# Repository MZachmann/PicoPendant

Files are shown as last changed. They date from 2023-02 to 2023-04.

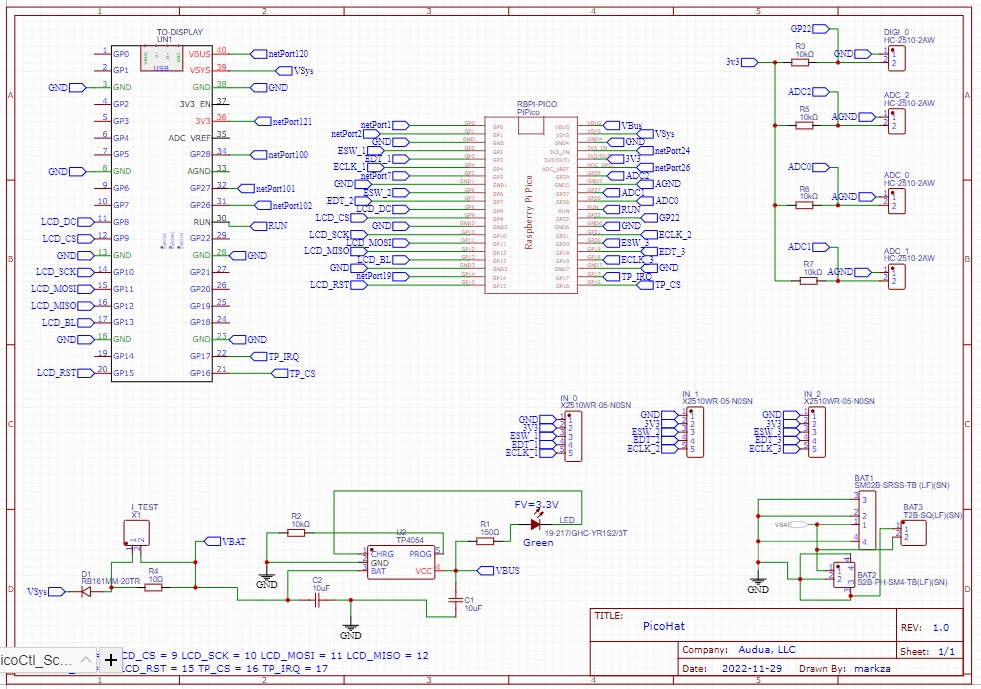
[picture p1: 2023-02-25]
CircuitBoard/images/Schematic_V1_02.jpg

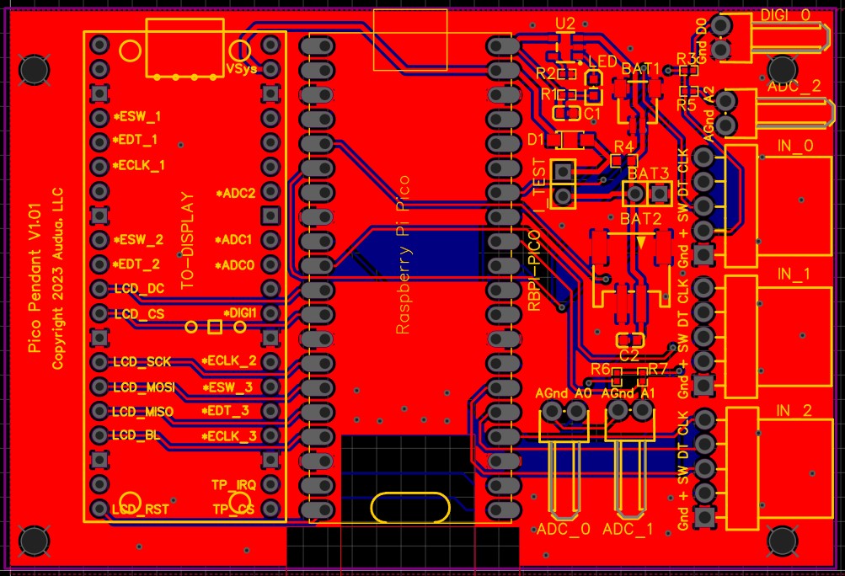
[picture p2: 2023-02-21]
CircuitBoard/images/PCB_Top_V1_01.jpg

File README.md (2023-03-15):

# PicoPendant
A small wireless CNC Pendant based off the Raspberry Pi Pico W and the Waveshare Pico-ResTouch-LCD-3.5. 

The pendant uses WiFi to communicate with the CNC and can work with any CNC/Mill/3d printer device that is available on a network. The current Micropython source only supports Duet3d-based controllers because that's all I have.

## Folders
* CircuitBoard<br>This contains the circuit board (display hat) files and readme. The circuit board has two LiPo connectors (small and regular), a LiPo charger, three encoder inputs, three A/D dividers for ladder switches and one switch input.
* Enclosure<br>This contains a Fusion360 workspace and result STL files for 3d printing an enclosure and spacers. The spacers are used to support the display hat over the Waveshare LCD. Since the hole locations are not exact and Jlcpcb seems unable to put holes in the right place anyway, the spacers are slightly offset.
* PythonSrc<br>The MicroPython source code

## Getting Started

You may need to install a driver to have the Pico show up as a serial port. See the Raspberry Pi Pico documentation.

### Installing MicroPython
* Plug the Pico into a USB port.
* Boot the Pico W. If it's connected to the display use the display reboot button, otherwise just power up the USB port.
* While booting, hold down the white button on top of the Pico. This will attach a drive to the PC.
* Copy the latest Micropython UF2 file to the attached Pico drive. When the copy is complete the Pico will reboot and Python will be installed.

### Start up Visual Studio Code
* Install Visual Studio Code
* Add these extensions (at least)
  * Python - adds intellisense for python
  * Pymakr - this plugin adds USB serial support for the Pico
* Start up Visual Studio Code and open the source folder. You should be prompted to load the PicoPendant.code-workspace as a Workspace and that links in the Pymakr usb serial extensions.

### Synching and copying files
* In Visual Studio Code switch to the pymakr extension icon in the left toolbar
* You may need to select the Pico COM port (ensure any driver is installed)
* As you mouse over the USB Serial Device line under PROJECTS / PicoPendant you'll see some icons appear (yeah bad UI)
  * Click the lightning bolt icon to connect to the Pico USB Serial
  * Click the box/prompt icon to open a terminal connected to the Pico
* To copy a file to the Pico:
  * Right click the file name and use the pymakr menu to select Upload to device
* To synchronize all files to the pico:
  * Mouse over the USB Serial Device line in the pymakr extension and pick the arrow-to-cloud icon (yeah bad UI)

### config.json
The code sets up default globals then reads config.json to override them. It's simple to manually edit your config.json and set up networking variables. Put config.json in the root with main.py to have it loaded at startup. Interrupt (Ctrl-C) the running jog.py and use

	from util import picoPendant
	picoPendant.GlobalPico().Save()

to save current settings. Clean out the stuff you don't want changed, then edit the stuff you want to override.

## SBC Support
The SBC version of the Duet3d controller takes quite a different WiFi syntax and is not yet supported.

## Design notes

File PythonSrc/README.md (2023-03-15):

# PicoPendant

## Overview
PicoPendant is a very simple product. It contains a Raspberry Pi Pico W, a [optional touchscreen] display, and a board that provides support for a LiPo alternate power source with charger from the USB. The board also has output pins providing raw access to most of the unused Pico I/O pins in a form for easy attachment to rotary encoders, ladder switches and other simple I/O devices.

The micropython source workspace (this) uses the __pymakr__ Visual Studio Code extension to communicate with the Pico W. It can synchronize files between the Pico W and PC and is generally very convenient but a bit awkward.

## Source
The source is all standard __MicroPython__. It is divided into functional groups. I attempted to use asynchronous I/O and a thread and both attempts failed miserably. Either it was running out of memory or too slow or ... anyway I pulled that stuff all out and it's just all blocking I/O for now. Maybe over time the threading will improve because network threaded is so obvious.

## GUI
The current gui is a single screen named 'Jog'. To run the jog screen requires the following MicroPython

	import runjog

The current GUI supports two rotary encoders and one ladder switch.

The leftmost encoder does the jogging. Click the switch to move between metric and inches and also to show/hide machine coordinates, so four positions.

The middle encoder is multi-use but primarily sets the jog amount per click. When the button is clicked the jog amount becomes enabled/disabled and an asterisk appears - this is a safety measure. If the middle encoder is disabled then tapping the touchscreen is also disabled.

The right switch sets the axis being jogged. 

To switch devices, tap the touchscreen and the middle encoder mode changes to device select. Tap again to have the middle encoder change screen brightness. Tap one more time to return to jog amount selection.

To exit cleanly from RunJogger press both rotary encoder buttons at the same time.

<span style="color:orange">There are 2 'safety' things to ensure the jogger isn't fussing your machine during jobs.</span>
* it only sends wifi requests when the encoder mode is 'adjust tic size' (enabled or disabled)
* you can use a Null device (0.0.0.0) to disable wifi requests

## Serialization
There is code to serialize/load the current settings. The load happens at start (main.py) but currently there is no automatic configuration save so that is a manual python call.

	from util import picoPendant
	picoPendant.GlobalPico().Save()

The configuration loader reads config.json and updates any fields found in config.json that exist in GlobalPico()).

## Known Concerns
* Touchscreen<br>
Currently the touchscreen location can not be read because this requires a much slower SPI speed and trying to temporarily switch the SPI speed to accomodate the touch location reader causes WiFi, which also uses SPI, to start failing permanently. So for now the touch location is not used. 
* Performance<br>
At this point I've switched to asyncio for the networking since threads were never going to work afaik. This works remarkably well so just tweaky timing things now.
* Rotary Encoders<br>
The current switch-based encoders are pretty weak (coarse and rare step-loss) but very cheap - the usual tradeoff. Using a real optical encoder for the movement rotary would help and I may switch to that at some point since I have one lying around.
* MicroPython<br>
Both MicroPython and CircuitPython are still in beta for the Raspberry Pi Pico W and it shows. CircuitPython is unstable, has no thread support, and the wifi support is very bad so imho unsuitable.  MicroPython has been stable and usable but I haven't yet gotten thread to work with networks.
* Random jogging<br>
To avoid any possible jogging while running a job, the code supports setting device to null (ip = 0.0.0.0) which will not send wifi requests. Also, wifi is disabled unless the middle encoder is in adjust-tic-size mode (enabled or disabled). 

## Folders

### display

Support code for drawing on the LCD along with app color theme and a simple text box. There's text support for loaded proportional fonts that can easily be created from TrueType.

* lcdDriver is mainly hardware dependent stuff
* dispUtil is only for test/demo stuff
* ioBox is a text box
* colorSet is a few color dictionaries incuding a primitive theme

### fonts

The fonts are stored as importable .py files that produce b/w font masks - but that is incredibly memory inefficient so instead the fontReader code manually reads the files, skips some steps, and produces the allocated bytearrays efficiently. For the really large digits, which change a lot, the fontDrawer draws them in a framebuffer and the fontCache dumbly blits predrawn characters for more speed. In my experience the pymakr extensions fail miserably without about 64K of free memory.

### screens

A very early gui. I want to see what gui things will be in use before spending time writing a more general probably xml-like generator.
* screens is the base class. 
* jog is the first 'screen' and currently it uses one textbox per field.

### util

One file per utility type. 
* two network connection modules (AP and STA)
* standard 'arduino' rotary encoder module
* ladder switch module<br> a switch where the pins are connected by roughly equal resistor values and two wires go to an A/D with known resistive divider. 
* picoPendant has the global data storage dictionary sets
  * one serialized
  * one full of created objects
 
The board has 3 encoder ports, 3 ladder sw or general A/D ports with 10K divider, and one digital switch input.

### web

* wifiConnect is the wifi connection method
* arequest is async urequests

### root files

* boot.py - pretty slim but does the global initialization
* main.py - allocates the font bytearrays, the display buffer and the caches and then does network initialization
* secrets_file.py - storage of wifi SSID and password for first runs or if loading GlobalPico's config.json fails
* convertFonts - a standalone CPython module to convert bitmap fonts to .py

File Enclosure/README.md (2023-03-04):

# Enclosure
The enclosure is designed to be 3d printed. 

The component to be printed is named Pendant.
The design is a sandwich with 3 pieces: the front (or top in the fusion design), the middle, and the back. There is an extra body that's tough to delete due to fusion360 but isn't printed. The front and back connect to the middle with short M3 screws.

## Steps:

1. Solder a set of pins into the leftmost socket location. These will plug into the display board.
2. Solder the Pico W into the center socket location either flush-mounted or with pins.
3. Print 4 spacers and screw their posts into the 4 M2.5 spots on the display. Then place the hat onto the display and use 4 short M2.5 screws to tighten down the hat (note in my photo I used 3 screws and spacers, which is fine). You can rotate the spacers slightly to add additional space and ensure the hat is parallel to the display board.
4. Insert the two encoders and ladder switch. The encoders go in horizontally to save space (this should be obvious from the encoder slots).
5. Lightly place the display into the front piece.
6. Attach whatever wires you need. There's very little excess space on the right of the encoder connectors so I squeeze the wires down or up to fit into the middle.
7. With some urging slide the middle piece fingers into the display assembly and set the middle on the front. Ensure the 3 fingers push down lightly on the display board. My front bows out a tiny bit due to the pressure. The front really could use 6 screws but...
8. Screw the front to the middle. I used M3x8 screws.
9. Insert the battery. Mine is very small (about 2 hours of usage I think) and fits above the bare leftmost socket but put it wherever.
10. Screw the back to the middle with another 4 short M3 screws.

## Holes:

There are 4 holes in the enclosure.

1. On top, there's a rectangular space to plug in a micro-usb connector for charge/serial.
2. Near that is a round hole to push a wire in - to click the switch to reboot the Pico.
3. On the back are two holes. The switch in the round hole can be held down during reset to get the usual attached disk drive for updating Micropython.
4. The rectangular hole lets you remove the berg jumper and then test the current flow.

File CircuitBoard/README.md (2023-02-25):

# CircuitBoard
This folder contains the json files for EasyEda as well as a few images to show the board.

There is a version 1.5 board that moves the parts to the left and the connectors inward but I haven't finalized the PCB and probably never will since the 1.01 board works fine for me but is a bit wider than desired.

Note that the power test pin should be jumpered in normal use.

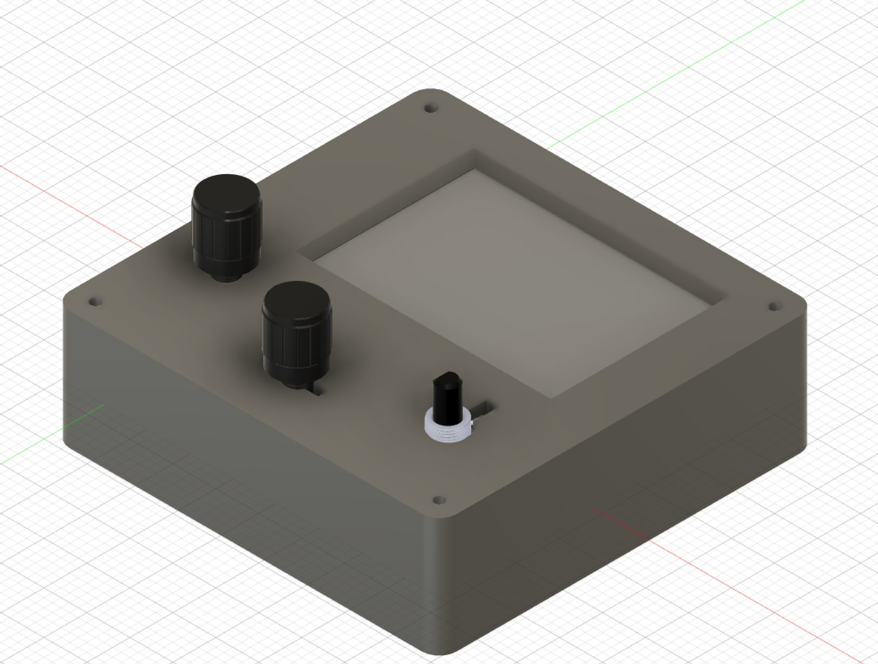
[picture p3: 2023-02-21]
Enclosure/images/Enclosure_V34.jpg

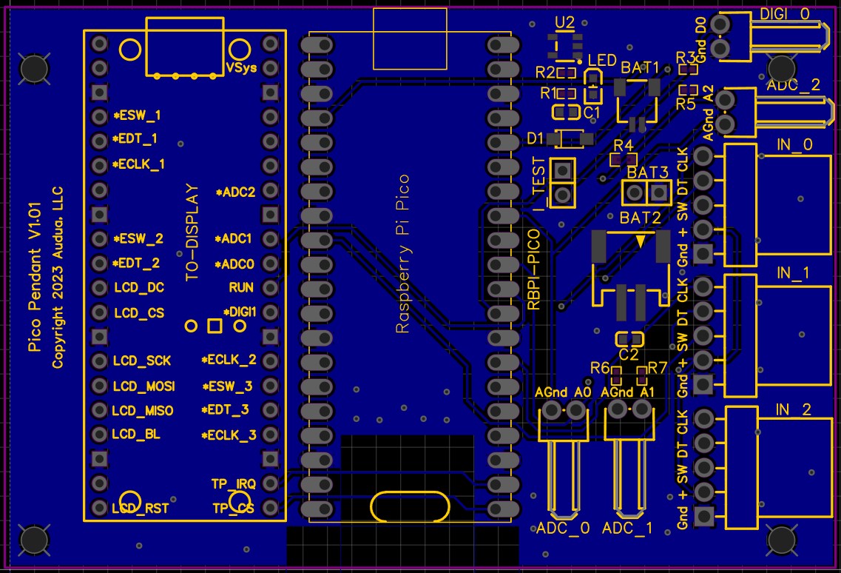
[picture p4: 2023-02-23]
CircuitBoard/images/PCB_Bottom_V1_02.jpg

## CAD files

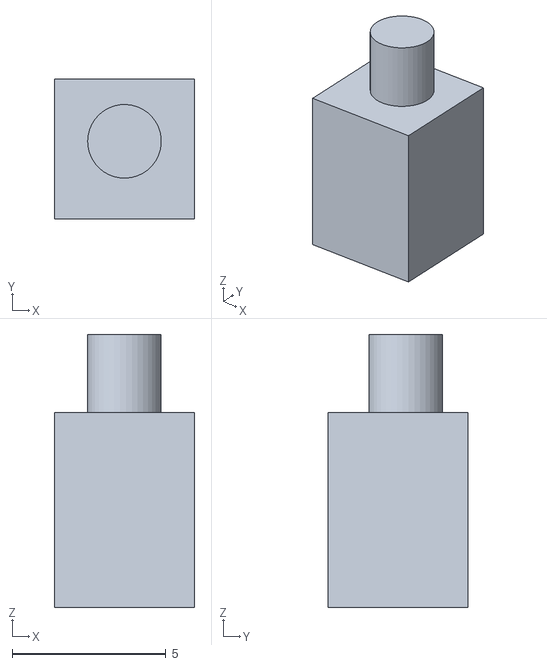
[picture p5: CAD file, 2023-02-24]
Enclosure/PicoPendant_Spacer.stl
4.57 x 4.57 x 8.89

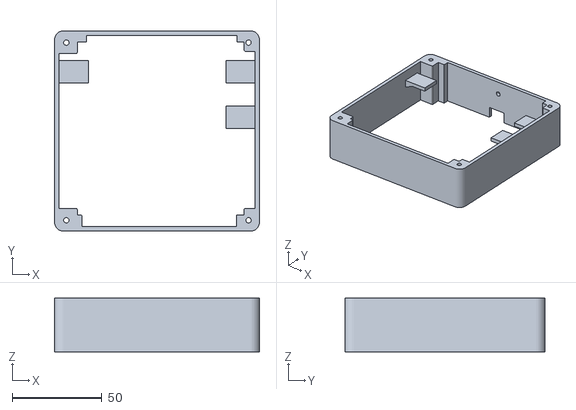
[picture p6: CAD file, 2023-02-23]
Enclosure/PicoPendant_Middle.stl
114.3 x 111.8 x 29.8

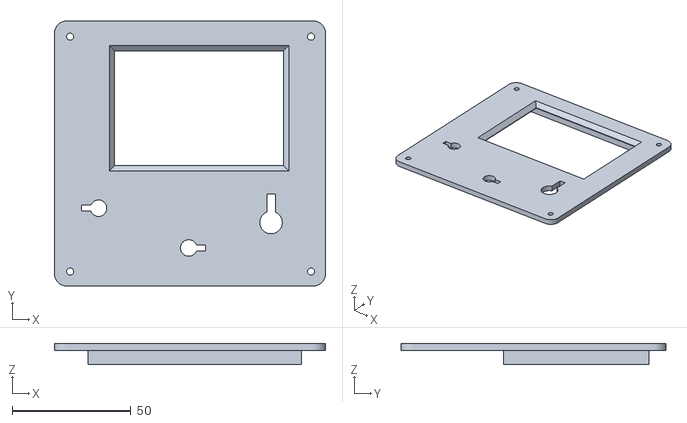
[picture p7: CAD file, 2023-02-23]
Enclosure/PicoPendant_Front.stl
114.3 x 111.8 x 8.89

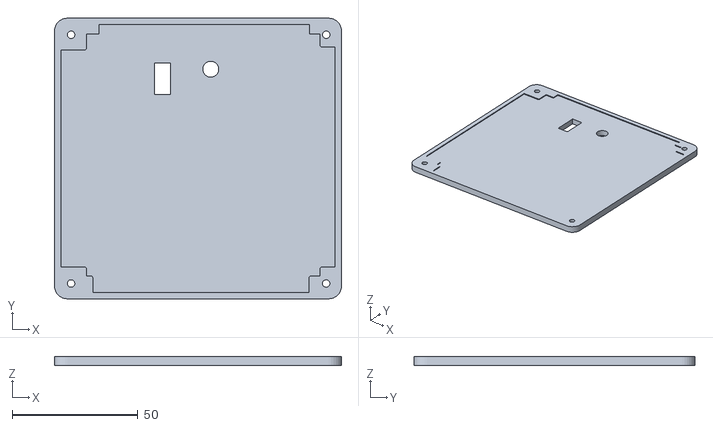
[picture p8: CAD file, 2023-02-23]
Enclosure/PicoPendant_Back.stl
114.3 x 111.8 x 3.50

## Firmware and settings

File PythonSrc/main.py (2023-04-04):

# this is a torturous bit of code intended to maximize heap storage usage
# the fonts and globalobjects are large chunks of ram as is the lcd so they are all
# allocated first
# then the network is connected
try:
	from util.picoPendant import GlobalObjects
	# initialize some storage
	GlobalObjects().Initialize()
	from fonts import fontCache
	from display.lcdDriver import GlobalLcd
	# initialize more storage now
	fontCache.FontCache().OccupyFontCache(GlobalObjects(), GlobalLcd())
	# finally connect
	from web import wifiConnect
except Exception as e:
	print(str(e))

from utime import sleep_ms
sleep_ms(2000)
import runjog

	

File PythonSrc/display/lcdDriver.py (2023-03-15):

from machine import Pin,SPI,PWM
import framebuf
from utime import sleep_ms, sleep_us
from util.picoPendant import GlobalObjects
from fonts.fontCache import FontCache
from fonts.fontDrawer import FontDrawer
from machine import disable_irq, enable_irq

# --------------------------------------------------------------------------
# a small amount of support for the waveshare display Pico-ResTouch-LCD-3.5
# the display is 480x320 
# the pins for the display are defined by the hardware and fixed
# --------------------------------------------------------------------------

LCD_DC   = 8
LCD_CS   = 9
LCD_SCK  = 10
LCD_MOSI = 11
LCD_MISO = 12
LCD_BL   = 13
LCD_RST  = 15
TP_CS    = 16
TP_IRQ   = 17

# a single instance is created when this file is imported
def GlobalLcd() :
    return _GlobalLcd

# the display class and some helpers
class LCD_3inch5():

    def __init__(self):
        # RGB565
        # self.RED   =   0x07E0
        # self.GREEN =   0x001f
        # self.BLUE  =   0xf800
        self.SLOWSPEED = 12_000_000
        self.HIGHSPEED = 64_000_000
        
        self.cs = Pin(LCD_CS, Pin.OUT)
        self.rst = Pin(LCD_RST, Pin.OUT)
        self.dc = Pin(LCD_DC, Pin.OUT)

        self.sck = Pin(LCD_SCK)
        self.mosi = Pin(LCD_MOSI)
        self.miso = Pin(LCD_MISO)
        
        self.tp_cs =Pin(TP_CS, Pin.OUT)
        self.irq = Pin(TP_IRQ, Pin.IN)
        self.irq.irq(trigger=Pin.IRQ_FALLING, handler=self.handle_touch)
        self.inTouch = False

        self.cs(1)
        self.dc(1)
        self.rst(1)
        self.tp_cs(1)
        # empirically the Pico works at 64MHz and quite well but any power of 2 divisor here works
        # all the way down to 4MHz were tested
        # the high speeds work fine with the display but the touch needs a much slow spi
        # touch=4MHz, display=64MHz
        self.spi = SPI(1, self.HIGHSPEED, sck=self.sck, mosi=self.mosi, miso=self.miso) # , bits=8, polarity=1, phase=1

        self.touchX  = 0.0
        self.touchY  = 0.0
        self.downX  = 0.0
        self.downY  = 0.0
        self.touchDown = False

        self.bufheight = 32         # allocated amount of data
        self.bufwidth = 480
        self.displayWidth = 480     # physical display dimensions
        self.displayHeight = 320
        self.buffer = GlobalObjects()['dispBuffer'] # bytearray(self.bufwidth * self.bufheight * 2)
        self.set_frame_size(self.bufwidth, self.bufheight)  # default size
        self._pwm = PWM(Pin(LCD_BL))
        self._init_display()

    def _write_cmd(self, cmd):
        self.cs(1)
        self.dc(0)
        self.cs(0)
        self.spi.write(bytearray([cmd]))
        self.cs(1)

    def _write_data(self, buf):
        self.cs(1)
        self.dc(1)
        self.cs(0)
        self.spi.write(buf)
        self.cs(1)

    def _writeCommand(self, cmd, buf = None):
        self._write_cmd(cmd)
        if buf is not None:
            hf = len(buf)
            for i in range(0, hf):
                self._write_data(bytearray([buf[i]]))

    def _writeOne(self, cmd, buf):
        self._write_cmd(cmd)
        self._write_data(bytearray([buf]))

    def _init_display(self):
        '''Initialize display'''
        self.rst(1)
        sleep_ms(5)
        self.rst(0)
        sleep_ms(10)
        self.rst(1)
        sleep_ms(5)
        self._writeOne(0xC2,  0x33)     # Power Ctrl 3
        self._writeCommand(0xC5, b"\x00\x1e\x80") # VCom
        # self.writeCommand(0x20)       # display inversion off
        self._writeOne(0xB1, 0xB0)      # frame rate control - Fosc @ 68.36
        self._writeOne(0x36, 0x28)      # memory access control - rowcol exchange, BGR
        self._writeCommand(0x21)        # display inversion on
        self._writeCommand(0xE0, b"\x00\x13\x18\x04\x0f\x06\x3a\x56\x4d\x03\x0a\x06\x30\x3e\x0f") # gamma 1
        self._writeCommand(0xE1, b"\x00\x13\x18\x01\x11\x06\x38\x34\x4d\x06\x0d\x0b\x31\x37\x0f") # gamma 2
        self._writeOne(0X3A, 0x55)      # pixel format set 16 bpx 65K colors
        self._writeCommand(0x11)        # sleep off
        sleep_ms(120)
        self._writeCommand(0x29)        # display on
        self._writeCommand(0xB6, b"\x00\x62") # display function 
        self._writeOne(0x36, 0x28)      # memory access control - rowcol exchange, BGR

    def set_frame_size(self, w, h):
        ''' create a new FrameBuffer representing the desired rectangle
        but don't reallocate the base bytearray buffer '''
        self.width = w      # for purposes of graphic operations set the implied size
        self.height = h
        self._MyFrame = framebuf.FrameBuffer(self.buffer, self.width, self.height, framebuf.RGB565)
        # print('completed %d x %d' % (self.width, self.height))
        
    def show_rect(self, block):
        ''' copy the framebuffer into a block, for testing '''
        xMin = 0
        yMin = block * self.height
        xMax = self.width - 1
        yMax = yMin + self.height - 1
        self.show_area(xMin, yMin, xMax, yMax)

    def show_area(self, xMin, yMin, xMax, yMax):
        ''' copy the framebuffer into a rectangular piece of the display '''
        xMin = int(xMin)
        xMax = int(xMax)
        yMin = int(yMin)
        yMax = int(yMax)
        # state = disable_irq() # given touch code issues this is probably necessary
        tos = [xMin>>8, xMin&0xff, xMax>>8, xMax&0xff]
        self._writeCommand(0x2A, bytearray(tos)) # col address
        tos = [yMin>>8, yMin&0xff, yMax>>8, yMax&0xff]
        self._writeCommand(0x2B,  bytearray(tos)) # row address
        self._write_cmd(0x2C)
        self.cs(1)
        self.dc(1)
        self.cs(0)
        self.spi.write(self._MyFrame)
        self.cs(1)
        # enable_irq(state)

    def set_brightness(self, duty):
        ''' change the backlight brightness by altering a PWM pin '''
        self._pwm.freq(1000)
        if(duty>=100):
            self._pwm.duty_u16(65535)
        else:
            self._pwm.duty_u16((int)(65535*duty/100))

    def draw_point(self,x,y,color):
        self._MyFrame.pixel(x,y,color)

    def touch_get(self, clear=False) :
        ''' return [status, downX, downY, touchX, touchY], clear status if requested '''
        x = [self.touchDown, self.downX, self.downY, self.touchX, self.touchY]
        if clear :
            self.touchDown = False
        return x
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

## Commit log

2023-02-23 Update fusion enclosure
2023-02-23 slight readme updates, add Null device
2023-02-23 align enclosure holes
2023-02-23 add enclosure readme
2023-02-23 add STL files for enclosure
    [PicoPendant_Back.stl, PicoPendant_Front.stl, PicoPendant_Middle.stl]
2023-02-24 update readmes, add spacer STL
    [PicoPendant_Spacer.stl]
2023-02-25 add RUN to schematic
2023-02-25 switch to one iobox per field
2023-03-04 thread attempt 3
2023-03-09 add support for multiple wifi nets slight improvement to encoders
2023-03-10 improve switch bounce, fix wifi connect
    [encoder.py, lcdDriver.py]
2023-03-15 switch async code. try 2.
2023-03-15 remove synchro/threaded network stuff
2023-03-15 fixup touch on jog. slight cleanups
    [jog.py, lcdDriver.py, picoPendant.py]
